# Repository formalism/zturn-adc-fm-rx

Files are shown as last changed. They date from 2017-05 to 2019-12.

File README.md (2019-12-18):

# zturn-adc-fm-rx
FM radio reciever by custom ADC/FM BPF board and [Z-turn board](http://www.myirtech.com/list.asp?id=502).

# Directory structure
 * FPGA : FPGA design which should be programmed to Z-turn board.
 * Firmware : programs to be run on Linux on Z-turn board.
      + adc-cap : communicates with adc-capture program.
      + ws-rust : use canvas.html to see FFT result (the functionality is similar to adc-cap and adc-capture program).
 * Sch : Schematics by KiCad
      + adc : ADC(LTC2292 by Linear Technology) board to be used with Z-turn board.
      + fm-bpf : FM bandpass active filter by PSA4-5043+ of Mini-Circuits.
 * PC : software run on Windows
      + adc-capture : communicates with above adc-cap firmware. Written in C#.
      + rf_demod : PC only implementation of FM demodulation. This program convers data captured by ADC to audio data. This program was written to verify algorithm to be implemented in FPGA.

Please see the following pages for more info.

https://www.living-in.tokyo/post/2018/2/new_fm_antenna/

https://www.living-in.tokyo/post/2017/09/new_adc_arrival/

https://www.living-in.tokyo/post/2017/08/adc_rev02/

https://www.living-in.tokyo/post/2017/07/fm_bpf3/

# License
MIT

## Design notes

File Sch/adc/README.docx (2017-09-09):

# PCB Spec

Layers: 4 layers

Material Details: FR4-Standard

Board Thickness: 1.6mm

Board Dimensions: Width 69.600mm x Height 43.800mm

Surface Finish: Lead Free HASL

Copper Thickness: 1oz (35um)

Soldermask Sides: Both

Soldermask Color: Green

Silkscreen Sides: Both

Silkscreen Color: White

# Description of the files contained:

*.drl (Drill Data)

*-drl.rpt (Drill Tool List)

*-drl_map.gbr (Drill Map)

*-Edge.Cuts.gbr (Board Outline)

*-top.pos (Top Layer Module Positions)

Top layer

*-F.Adhes.gbr (Gerber Top Layer Adhesives)

*-F.Cu.gbr (Gerber Top Layer)

*-F.Mask.gbr (Gerber Top Solder Mask)

*-F.Paste.gbr (Gerber Top Solder Paste for stencil)

*-F.SilkS.gbr (Gerber Top Silk)

2nd layer

*-In1.Cu.gbr (Gerber 2nd layer)

3rd layer

*-In2.Cu.gbr (Gerber 3rd layer)

Bottom layer

*-B.Adhes.gbr (Gerber Bottom Layer Adhesives)

*-B.Cu.gbr (Gerber Bottom Layer)

*-B.Mask.gbr (Gerber Bottom Solder Mask)

*-B.Paste.gbr (Gerber Bottom Solder Paste for stencil)

*-B.SilkS.gbr (Gerber Bottom Silk)

BOM file: zturn_adc.xlsx

# Note for Assembly

All the components are chosen carefully including passives. So use the part as-is where BOM column “Compatible parts can be used?” is marked “N”. If you cannot procure the parts as specified in BOM file, please let me know the suggested parts and their datasheets.

All the parts are mount on the TOP SIDE.

Do not load R29, R30 (and NO SOLDER).

4 center pads of U1, U6 should also be soldered.

CN3 is towards OUTSIDE of the PCB.

Take care of the orientation when mounting the following parts: U1, U2, U3, U4, U5, U6, X1, T1. Pin #1 is marked with triangle “△”.

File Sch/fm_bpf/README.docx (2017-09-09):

# PCB Spec

Layers: 2 layers (top and bottom)

Material Details: FR4-Standard

Board Thickness: 0.6mm (not 1.6mm!!)

Board Dimensions: Width 40.200mm x Height 20.800mm

Surface Finish: Lead Free HASL

Copper Thickness: 1oz (35um)

Soldermask Sides: Top

Soldermask Color: Green

Silkscreen Sides: Both

Silkscreen Color: White

# Description of the files contained:

*.drl (Drill Data)

*-drl.rpt (Drill Tool List)

*-drl_map.gbr (Drill Map)

*-Edge.Cuts.gbr (Board Outline)

*-top.pos (Position of the modules on Top Layer)

Top Layer

*-F.Adhes.gbr (Gerber Top Layer Adhesives)

*-F.Cu.gbr (Gerber Top Layer)

*-F.Mask.gbr (Gerber Top Solder Mask)

*-F.Paste.gbr (Gerber Top Solder Paste for stencil)

*-F.SilkS.gbr (Gerber Top Silk)

Bottom Layer

*-B.Adhes.gbr (Gerber Bottom Layer Adhesives)

*-B.Cu.gbr (Gerber Bottom Layer)

*-B.Mask.gbr (Gerber Bottom Solder Mask)

*-B.Paste.gbr (Gerber Bottom Solder Paste for stencil)

*-B.SilkS.gbr (Gerber Bottom Silk)

BOM file: fm_bpf.xlsx

# Note for Assembly

All the components are chosen carefully including passives. So use the part as-is where BOM column “Compatible parts can be used?” is marked “N”. If you cannot procure the parts as specified in BOM file, please let me know the suggested parts and their datasheets.

All the parts are mount on the TOP SIDE.

Because the PCB is thin, soldering on bottom side for the SMA connector is not necessary (top side is necessary).

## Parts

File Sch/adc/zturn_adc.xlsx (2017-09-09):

Reference | Value | Footprint | Datasheet | Type | Qty | Part | Manufacturer | Description | Compatible can be used? | Note
U1 | LTC2292 | 64QFN | http://cds.linear.com/docs/en/datasheet/229321fa.pdf | SMD | 1 | LTC2292CUP#PBF | Linear Technology | 12 Bit Analog to Digital Converter 2 Input 2 Pipelined 64-QFN (9x9) | N | Take Care of Rotation
P1 | CONN_02X40 | adc_lib:20021121-00080T4LF | http://portal.fciconnect.com/Comergent//fci/drawing/20021121.pdf | SMD | 1 | 20021121-00080T4LF | Amphenol FCI | CONN HEADER 80POS DL UNSHRD SMD | Y
J1,J3,J4 | JP2 |  | https://cdn.harwin.com/pdfs/M20-998.pdf | PTH | 3 | M20-9980245 | Harwin Inc. | DIL VERTICAL PC TAIL PIN HEADER 4 POS | Y
TP1,TP2,TP3,TP4 | TEST |  |  |  |  |  |  |  |  | Do Not Load
W1,W2,W3,W4,W5,W6 | TEST_1P |  | http://portal.fciconnect.com/Comergent//fci/drawing/68000.pdf | PTH | 6 | 68000-401HLF | Amphenol FCI | BERGSTIK II .100" SR STRAIGHT | Y
C9,C15,C16,C22,C23, C24,C26,C38,C39 | 0.1uF | 0603 | http://search.murata.co.jp/Ceramy/image/img/A01X/G101/ENG/GRM188R71H104JA93-01.pdf | SMD | 9 | GRM188R71H104JA93D | Murata Electronics North America | CAP CER 0.1uF ±5% 50V X7R 0603 | N
C3,C4,C5,C7,C8,C10,C11, C13,C14,C25,C29,C30, C41,C44,C46,C53 | 0.1uF | 0402 | http://search.murata.co.jp/Ceramy/image/img/A01X/G101/ENG/GRM155R71C104KA88-01.pdf | SMD | 16 | GRM155R71C104KA88J | Murata Electronics North America | CAP CER 0.1uF ±10% 16V X7R 0402 | N
C28,C42,C43,C45,C47 | 4.7uF | 0603 | http://ds.yuden.co.jp/TYCOMPAS/ut/detail.do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 | SMD | 5 | EMK107ABJ475KA-T | Taiyo Yuden | CAP CER 4.7uF ±10% 16V X5R 0603 | Y
C6,C31,C32,C40 | 2.2uF | 0402 | http://search.murata.co.jp/Ceramy/image/img/A01X/G101/ENG/GRM155R61A225KE95-01.pdf | SMD | 4 | GRM155R61A225KE95D | Murata Electronics North America | CAP CER 2.2µF ±10% 10V X5R 0402 | Y
C33,C34,C35,C36 | 1uF | 0402 | http://ds.yuden.co.jp/TYCOMPAS/ut/detail.do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 | SMD | 4 | EMK105BJ105KV-F | Taiyo Yuden | CAP CER 1uF ±10% 16V X5R 0402 | Y
C1,C2,C12,C20 | 1uF | 0603 | http://psearch.jp.murata.com/capacitor/product/GCM188R71E105KA64%23.pdf | SMD | 4 | GCM188R71E105KA64D | Murata Electronics North America | CAP CER 1uF ±10% 25V X7R 0603 | N
C17 | 12pF | 0603 | http://search.murata.co.jp/Ceramy/image/img/A01X/G101/ENG/GRM1885C1H120JA01-01.pdf | SMD | 1 | GRM1885C1H120JA01D | Murata Electronics North America | CAP CER 12pF ±5% 50V NP0 0603 | N
C18 | 1000pF | 0603 | http://search.murata.co.jp/Ceramy/image/img/A01X/G101/ENG/GRM188R71H102KA01-01.pdf | SMD | 1 | GRM188R71H102KA01D | Murata Electronics North America | CAP CER 1000pF ±10% 50V X7R 0603 | N
C37 | 8pF | 0402 | http://psearch.en.murata.com/capacitor/product/GJM1555C1H8R0CB01%23.pdf | SMD | 1 | GJM1555C1H8R0CB01D | Murata Electronics North America | CAP CER 8pF ±0.25pF 50V C0G/NP0 0402 | N
C21,C27 | 220uF | 1206 | http://search.murata.co.jp/Ceramy/image/img/A01X/G101/ENG/GRM31CR60J227ME11-01.pdf | SMD | 2 | GRM31CR60J227ME11L | Murata Electronics North America | CAP CER '220µF ±20% 6.3V X5R 1206 | Y
R1,R3,R4,R9,R12 | 22 | 0603 | https://industrial.panasonic.com/cdbs/www-data/pdf/RDA0000/AOA0000C304.pdf | SMD | 5 | ERJ-3EKF22R0V | Panasonic Electronic Components | 22 Ohm ±1% 0.1W, 1/10W Chip Resistor 0603 (1608 Metric) | Y
R25 | 2k | 0603 | https://industrial.panasonic.com/cdbs/www-data/pdf/RDA0000/AOA0000C304.pdf | SMD | 1 | ERJ-3EKF2001V | Panasonic Electronic Components | 2k Ohm ±1% 0.1W, 1/10W Chip Resistor 0603 (1608 Metric) | Y
R7,R8 | 25 | 0603 | https://industrial.panasonic.com/cdbs/www-data/pdf/RDA0000/AOA0000C304.pdf | SMD | 2 | ERJ-3EKF24R9V | Panasonic Electronic Components | 24.9 Ohm ±1% 0.1W, 1/10W Chip Resistor 0603 (1608 Metric) | N
R5,R6,R24 | 1k | 0603 | https://industrial.panasonic.com/cdbs/www-data/pdf/RDA0000/AOA0000C304.pdf | SMD | 3 | ERJ-3EKF1001V | Panasonic Electronic Components | 1k Ohm ±1% 0.1W, 1/10W Chip Resistor 0603 (1608 Metric) | Y
R29,R30 | DNL | 0603 |  |  |  |  |  |  |  | Do Not Load
R21,R22,R23 | 10k | 0402 | https://industrial.panasonic.com/cdbs/www-data/pdf/RDA0000/AOA0000C304.pdf | SMD | 3 | ERJ-2RKF1002X | Panasonic Electronic Components | 10k Ohm ±1% 0.1W, 1/10W Chip Resistor 0402 (1005 Metric) | Y
R2,R10,R11,R16,R27,R28 | 10k | 0603 | https://industrial.panasonic.com/cdbs/www-data/pdf/RDA0000/AOA0000C304.pdf | SMD | 6 | ERJ-3EKF1002V | Panasonic Electronic Components | 10k Ohm ±1% 0.1W, 1/10W Chip Resistor 0603 (1608 Metric) | Y
R18,R19 | 25 | 0402 | https://industrial.panasonic.com/cdbs/www-data/pdf/RDA0000/AOA0000C304.pdf | SMD | 2 | ERJ-2RKF24R9X | Panasonic Electronic Components | 24.9 Ohm ±1% 0.1W, 1/10W Chip Resistor 0402 (1005 Metric) | Y
R31,R32 | 12 | 0402 | https://industrial.panasonic.com/cdbs/www-data/pdf/RDA0000/AOA0000C304.pdf | SMD | 2 | ERJ-2RFK12R0X | Panasonic Electronic Components | 12 Ohm ±1% 0.1W, 1/10W Chip Resistor 0402 (1005 Metric) | N
R20,R33 | 0 | 0603 | https://industrial.panasonic.com/cdbs/www-data/pdf/RDA0000/AOA0000C304.pdf | SMD | 2 | ERJ-3GEY0R00V | Panasonic Electronic Components | jumper 0.1W 1/10W Chip Resistor 0603 (1608 Metric) | Y
R34 | 680 | 0603 | http://www.yageo.com/documents/recent/PYu-RC_Group_51_RoHS_L_7.pdf | SMD | 1 | RC0603FR-07680RL | Yageo | RES SMD 680 ohm ±1% 1/10W 0603 | Y
R17 | 1M | 0603 | http://www.yageo.com/documents/recent/PYu-RC_Group_51_RoHS_L_7.pdf | SMD | 1 | RC0603FR-071ML | Yageo | RES SMD 1M ohm ±1% 1/10W 0603 | Y
R13 | 33 | 0603 | http://www.yageo.com/documents/recent/PYu-RC_Group_51_RoHS_L_7.pdf | SMD | 1 | RC0603FR-0733RL | Yageo | RES SMD 33 ohm ±1% 1/10W 0603 | Y
X1 | TCXO | 4-SMD | http://www.taitien.com/wp-content/uploads/2015/12/XO-0076_TX.pdf | SMD | 1 | TXETBLSANF-40.0000 | Taitien | OSC TCXO 40.0000 MHz CLP S SMD | N | Take Care of Rotation
U4,U5 | NC7SVU04-SC70 | SC-70-5 | https://www.fairchildsemi.com/datasheets/NC/NC7SVU04.pdf | SMD | 2 | NC7SVU04P5X | Fairchild/ON Semiconductor | Inverter IC unbuff SC70-5 | N
T1 | ETC1-1-13 | 5-SMD | http://cdn.macom.com/datasheets/ETC1-1-13.pdf | SMD | 1 | ETC-1-1-13 | M/A-Com Technology Solutions | RF balun 4.5MHz-3GHz 1:1 5-SMD | N
U2,U3 | LP5907_SOT-23 | SOT-23-5 | http://www.ti.com/lit/ds/symlink/lp5907-q1.pdf | SMD | 2 | LP5907QMFX-3.0Q1 | Texas Instruments | Linear Voltage Regulator IC Positive Fixed Output 3V 250mA SOT-23-5 | N | Take Care of Rotation
L3 | 8.2uH | 1008 | http://www.murata.com/~/media/webrenewal/products/inductor/chip/tokoproducts/wirewoundmetalalloychiptype/m_dfe252012f.ashx | SMD | 1 | DFE252012F-8R2M=P2 | Murata Electronics North America | shielded FIXED IND 8.2uH 1.1A 410mOhm | N
L4 | 3.3uH | 1008 | http://www.murata.com/~/media/webrenewal/products/inductor/chip/tokoproducts/wirewoundmetalalloychiptype/m_dfe252012f.ashx | SMD | 1 | DFE252012F-3R3M=P2 | Murata Electronics North America | shielded FIXED IND 3.3uH 1.8A 135mOhm | N
U6 | NAU8822LYG | 32-QFN | http://www.nuvoton.com/resource-files/NAU8822LDataSheetRev1.9.pdf | SMD | 1 | NAU8822LYG | Nuvoton Technology Corporation of America | Audio Interface 24 b I²S, PCM 32-QFN (5x5) | N | Take Care of Rotation
CN1,CN2 | SMA | adc_lib:SMA_Edge | http://www.molex.com/pdm_docs/sd/732511150_sd.pdf | Edge Connector | 2 | 73251-1150 | Molex | CONN SMA RCPT STR 50OHM EDGE MNT | Y
CN3 | AudioJack | adc_lib:SJ-3523-SMT | http://www.cui.com/product/resource/sj-352x-smt-series.pdf | SMD | 1 | SJ-3523-SMT-TR | CUI Inc. | 3.50mm (0.141", 1/8", Mini Plug) - Headphone Phone Jack Stereo Connector Solder | Y
L1,L2,L7,L10 | Ferrite Bead | 0805 | https://product.tdk.com/info/en/catalog/datasheets/beads_commercial_power_mpz2012_en.pdf | SMD | 4 | MPZ2012S601AT000 | TDK Corporation | FERRITE BEAD 600 OHM 0805 1LN | Y
 |  |  |  | Total Components | 103
 |  |  |  | SMD | 92

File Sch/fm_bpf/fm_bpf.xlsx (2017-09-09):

Reference | Value | Footprint | Datasheet | Type | Qty | Part | Manufacturer | Description | Compatible parts can be used?
CN1,CN2 | SMA | Edge | https://belfuse.com/resources/Johnson/productinformation/pi-142-0701-881.pdf | Edge Connector | 2 | 142-0701-801 | Cinch Connectivity Solutions Johnson | SMA JACK STR 50ohm EDGE MNT | Y
U1 | LP5907_SOT-23 | SOT-23-5 | http://www.ti.com/lit/ds/symlink/lp5907-q1.pdf | SMD | 1 | LP5907QMFX-3.8Q1 | Texas Instruments | IC REG LDO 3.8V 0.25A SOT23-5 | N
U2 | PSA4-5043+ | MMM1362 | https://www.minicircuits.com/pdfs/PSA4-5043+.pdf | SMD | 1 | PSA4-5043+ | Mini-Circuits | ML AMPL / SURF MOUNT / RoHS | N
L1 | 330nH | 0603 | https://product.tdk.com/info/en/catalog/datasheets/inductor_commercial_standard_mlj1608_en.pdf | SMD | 1 | MLJ1608WR33JT000 | TDK Corporation | shielded FIXED IND ±5% 330nH 500mA 312mOhm (230MHz) | N
L2 | 27nH | 0603 | http://www.yuden.co.jp/productdata/catalog/en/mlci04_e.pdf | SMD | 1 | HK160827NJ-T | Taiyo Yuden | FIXED IND ±5% 27nH 300mA 450mOhm (1.4GHz) | N
L3 | 8.2uH | 1008 | http://www.murata.com/~/media/webrenewal/products/inductor/chip/tokoproducts/wirewoundmetalalloychiptype/m_dfe252012f.ashx | SMD | 1 | DFE252012F-8R2M=P2 | Murata Electronics North America | shielded FIXED IND ±20% 8.2uH 1.1A 410mOhm | N
L4 | 3.3uH | 0603 | https://media.digikey.com/pdf/Data%20Sheets/TDK%20PDFs/GLFR%20Series.pdf | SMD | 1 | GLFR1608T3R3M-LR | TDK Corporation | shielded FIXED IND ±20% 3.3uH 525mA 230mOhm | N
L5,L7 | 560nH | 0603 | https://product.tdk.com/info/en/catalog/datasheets/inductor_commercial_standard_mlj1608_en.pdf | SMD | 2 | MLJ1608WR56JT000 | TDK Corporation | shielded FIXED IND ±5% 560nH 400mA 520mOhm (170MHz) | N
L6 | 100nH | 0603 | https://product.tdk.com/info/en/catalog/datasheets/inductor_automotive_standard_mlf1608_en.pdf | SMD | 1 | MLF1608DR10JTD25 | TDK Corporation | shielded FIXED IND ±5% 100nH 200mA 350mOhm (450MHz) | N
C1,C4 | 1uF | 0603 | http://ds.yuden.co.jp/TYCOMPAS/ut/detail.do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 | SMD | 2 | TMK107B7105KA-T | Taiyo Yuden | CAP CER ±10% 1uF 25V X7R 0603 | N
C6,C7,C8 | 0.1uF | 0603 | http://search.murata.co.jp/Ceramy/image/img/A01X/G101/ENG/GRM188R71H104JA93-01.pdf | SMD | 3 | GRM188R71H104JA93D | Murata Electronics North America | CAP CER ±5% 0.1uF 50V X7R 0603 | N
C2 | 27pF | 0603 | http://search.murata.co.jp/Ceramy/image/img/A01X/partnumbering_e_01.pdf | SMD | 1 | GRM1885C1H270FA01D | Murata Electronics North America | CAP CER ±1% 27pF 50V C0G/NP0 0603 | N
C3 | 12pF | 0603 | http://search.murata.co.jp/Ceramy/image/img/A01X/partnumbering_e_01.pdf | SMD | 1 | GRM1885C1H120FA01D | Murata Electronics North America | CAP CER ±1% 12pF 50V C0G/NP3 0603 | N
C5 | 130pF | 0603 | http://search.murata.co.jp/Ceramy/image/img/A01X/partnumbering_e_01.pdf | SMD | 1 | GRM1885C1H131JA01D | Murata Electronics North America | CAP CER ±5% 130pF 50V C0G/NP3 0603 | N
C9 | 9pF | 0603 | http://search.murata.co.jp/Ceramy/image/img/A01X/partnumbering_e_01.pdf | SMD | 1 | GRM1885C1H9R0DA01D | Murata Electronics North America | CAP CER ±0.5pF 9pF 50V C0G/NP0 0603 | N
C11 | 68pF | 0603 | http://search.murata.co.jp/Ceramy/image/img/A01X/partnumbering_e_01.pdf | SMD | 1 | GRM1885C1H680FA01D | Murata Electronics North America | CAP CER ±1% 68pF 50V C0G/NP0 0603 | N
C12 | 100pF | 0603 | http://search.murata.co.jp/Ceramy/image/img/A01X/partnumbering_e_01.pdf | SMD | 1 | GRM1885C1H101JA01D | Murata Electronics North America | CAP CER ±5% 100pF 50V C0G/NP0 0603 | N
C10,C13,C14 | 5pF | 0603 | http://search.murata.co.jp/Ceramy/image/img/A01X/partnumbering_e_01.pdf | SMD | 3 | GRM1885C1H5R0BA01D | Murata Electronics North America | CAP CER ±0.1pF 5pF 50V C0G/NP0 0603 | N
R1 | 680 | 0603 | http://www.yageo.com/documents/recent/PYu-RC_Group_51_RoHS_L_7.pdf | SMD | 1 | RC0603FR-07680RL | Yageo | RES SMD 680 ohm 1% 1/10W 0603 | Y
R2 | 10k | 0603 | http://www.yageo.com/documents/recent/PYu-RC_Group_51_RoHS_L_7.pdf | SMD | 1 | RC0603FR-0710KL | Yageo | RES SMD 10k ohm 1% 1/10W 0603 | Y
W1,W2 | TEST_1P | PTH | http://portal.fciconnect.com/Comergent//fci/drawing/68000.pdf | PTH | 2 | 68000-401HLF | Amphenol FCI | BERGSTIK II .100" SR STRAIGHT | Y
 |  |  |  | total components | 29
 |  |  |  | SMD | 25

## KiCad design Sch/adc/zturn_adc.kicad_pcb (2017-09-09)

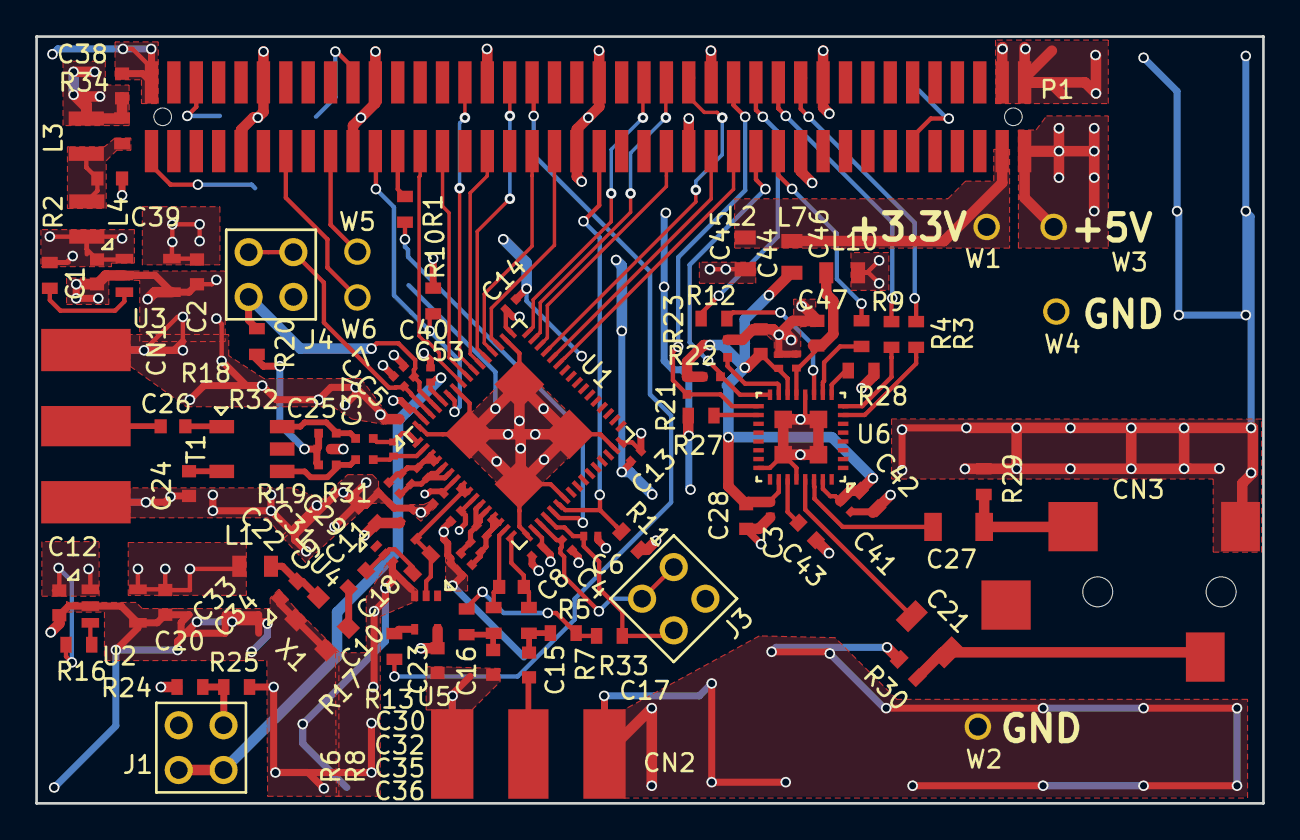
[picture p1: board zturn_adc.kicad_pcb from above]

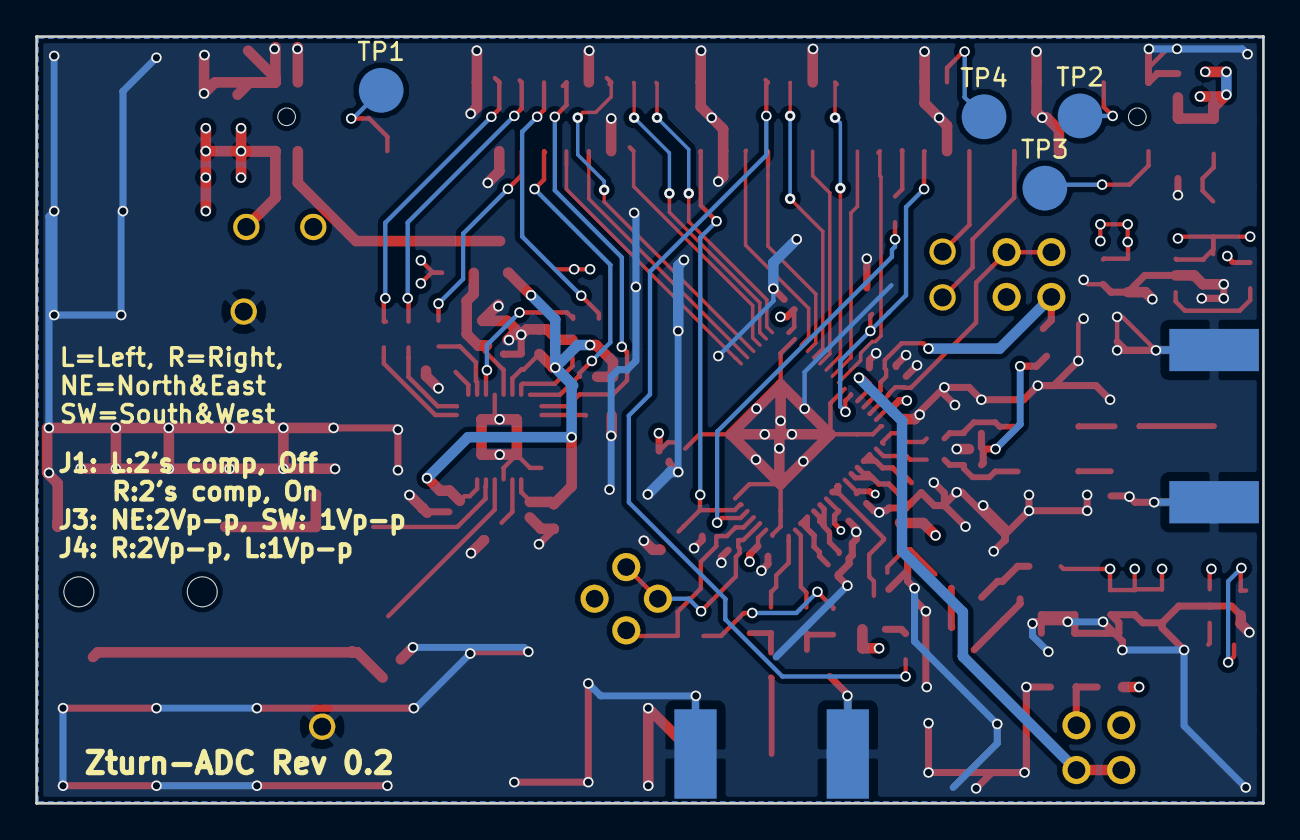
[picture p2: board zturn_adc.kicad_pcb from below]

Board: 4 copper layers, 69.6 x 43.5 mm, 109 parts (4 on the bottom side), 83 nets.

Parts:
C1, C2, C12, C20: 1uF X7R; C0603
C3, C4, C5, C7, C8, C10, C11, C13, C14, C41, C44, C46: 0.1uF; C0402
C6, C31, C32, C40: 2.2u; C0402
C9, C15, C16: 0.1uF; C0603
C17: 12pF; C0603
C18: 1000pF; C0603
C21, C27: 220uF; C1206
C22, C23, C24, C26, C38, C39: 0.1u; C0603
C25, C29, C30, C53: 0.1u; C0402
C28, C42, C43, C45, C47: 4.7uF; C0603
C33, C34, C35, C36: 1u; C0402
C37: 8p; C0402
CN1, CN2: SMA; SMA_Edge
CN3: AudioJack; SJ-3523-SMT
J1, J3, J4: JP2; M20-9980245
L1, L2, L7, L10: L; FB0805
L3: 8.2u; L1008
L4: 3.3u; L1008
P1: CONN_02X40; 20021121-00080T4LF
R1, R3, R4, R9, R12: 22; R0603
R2, R10, R11, R16, R27, R28: 10k; R0603
R5, R6, R24: 1k; R0603
R7, R8: 25; R0603
R13: 33; R0603
R17: 1M; R0603
R18, R19: 25; R0402
R20, R33: 0; R0603
R21, R22, R23: 10k; R0402
R25: 2k; R0603
R29, R30: DNL; R0603
R31, R32: 12; R0402
R34: 680; R0603
T1: ETC1-1-13
TP1, TP2, TP3, TP4: TEST; TL
U1: LTC2292
U2, U3: LP5907_SOT-23; LP5907
U4, U5: NC7SVU04-SC70; NC7SVU04-5SC70
U6: NAU8822LYG; NAU8822L
W1, W2, W3, W4, W5, W6: TEST_1P; 68000-401HLF
X1: TCXO

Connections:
+3V3: L2.2, L7.2, P1.3, W1.1
+5V: C38.1, L3.2, P1.1, R34.2, W3.1
/AudioDAC/VDDC: C46.1, C47.1, L10.1, U6.13
/AudioDAC/VREF: C43.1, U6.27
/CN/IO_B35_LN2: P1.24, R4.1
/CN/IO_B35_LN3: P1.29, U1.44
/CN/IO_B35_LN6: P1.34, U1.47
/CN/IO_B35_LN9: P1.45, U1.52
/CN/IO_B35_LN11: P1.49, U1.54
/CN/IO_B35_LN12: P1.48, U1.53
/CN/IO_B35_LN13: P1.55, U1.57
/CN/IO_B35_LN23: P1.79, TP3.1
/CN/IO_B35_LP1: P1.23, R9.1
/CN/IO_B35_LP2: P1.22, R3.1
/CN/IO_B35_LP3: P1.27, U1.43
/CN/IO_B35_LP4: P1.26, R12.2
/CN/IO_B35_LP5: P1.33, U1.46
/CN/IO_B35_LP6: P1.32, U1.45
/CN/IO_B35_LP8: P1.36, U1.48
/CN/IO_B35_LP9: P1.43, U1.51
/CN/IO_B35_LP13(MRCC): P1.53, U1.56
/CN/IO_B35_LP14: P1.52, U1.55
/CN/IO_B35_LP15: P1.57, R1.1
/CN/IO_B35_LP17: P1.63, W5.1
/CN/IO_B35_LP18: P1.62, TP4.1
/CN/IO_B35_LP19: P1.67, W6.1
/CN/IO_B35_LP24: P1.76, TP2.1
/CN/MUX: R1.2, U1.21
/CN/PS_MIO0: P1.11, TP1.1
/CN/SHDNA: P1.59, R10.1, U1.59
/CN/SHDNB: P1.39, R11.1, U1.22
/RF_in/CLK40M: R17.1, U1.8, U1.9, U4.4, U5.2
/RF_in/VCC5: C1.1, C12.1, L4.1, R2.1, R16.1, U2.1, U3.1
/RF_in/VCMA: C40.1, J4.3, R20.2, U1.61
/RF_in/VCMB: C6.1, J3.3, R33.1, U1.20
ADC_CLK: P1.46, R13.1
BCLK: R4.2, U6.8
DACIN: R9.2, U6.10
FS: R3.2, U6.7
GND: C1.2, C2.2, C3.2, C4.2, C5.2, C6.2, C7.2, C8.2, C9.1, C10.2, C11.2, C12.2, C13.2, C14.2, C16.2, C20.2, C22.2, C23.2, C24.1, C25.1, C28.2, C33.1, C34.1, C35.1, C36.1, C38.2, C39.2, C40.2, C41.2, C42.2, C43.2, C44.2, C45.2, C46.2, C47.2, C53.2, CN1.2, CN1.3, CN1.4, CN1.5, CN2.2, CN2.3, CN2.4, CN2.5, CN3.1, P1.2, P1.4, P1.20, P1.21, P1.30, P1.31, P1.40, P1.41, P1.50, P1.60, P1.61, P1.70, P1.71, P1.80, R10.2, R11.2, R23.2, R25.2, R27.2, R28.2, R29.2, R30.2, U1.17, U1.23, U1.31, U1.50, U1.58, U1.64, U1.65, U2.2, U2.4, U3.2, U3.4, U4.3, U5.3, U6.12, U6.24, U6.28, U6.33, W2.1, W4.1, X1.1, X1.2
MCLK: R12.1, U6.11
unnamed: C4.1, J3.2, J3.4, U1.19
unnamed: C5.1, J4.2, J4.4, U1.62
unnamed: C9.2, L1.2, X1.4
unnamed: C13.1, C14.1, L2.1, U1.32, U1.49
unnamed: C15.1, R5.2, R7.2
unnamed: C15.2, CN2.1
unnamed: C16.1, R6.2, R8.2
unnamed: C17.1, R7.1, U1.16
unnamed: C17.2, R8.1, U1.15
unnamed: C18.1, X1.3
unnamed: C18.2, R17.2, U4.2
unnamed: C21.1, U6.29
unnamed: C21.2, CN3.3, R30.1
unnamed: C24.2, T1.2
unnamed: C25.2, R18.2, R19.1, R20.1
unnamed: C26.1, T1.1
unnamed: C26.2, CN1.1
unnamed: C27.1, U6.30
unnamed: C27.2, CN3.2, R29.1
unnamed: C3.1, C28.1, C41.1, C42.1, C44.1, C45.1, L7.1, R21.1, R22.1, U6.14, U6.26, U6.31
unnamed: C29.1, C31.1, C33.2, U1.3, U1.4
unnamed: C29.2, C31.2, C34.2, U1.5, U1.6
unnamed: C30.1, C32.1, C35.2, U1.11, U1.12
unnamed: C30.2, C32.2, C36.2, U1.13, U1.14
unnamed: C37.1, R32.1, U1.1
unnamed: C37.2, R31.1, U1.2
unnamed: C39.1, L3.1, L4.2, R34.1
unnamed: C53.1, J1.2, J1.4, U1.60
unnamed: J1.3, R24.2, R25.1
unnamed: R2.2, U3.3
unnamed: R13.2, U5.4
unnamed: R16.2, U2.3
unnamed: R18.1, R32.2, T1.5
unnamed: R19.2, R31.2, T1.3
unnamed: R23.1, U6.15
unnamed: R27.1, U6.18
unnamed: R28.1, U6.9
unnamed: R5.1, R6.1, R33.2
SCL: P1.25, R22.2, U6.16
SDA: P1.28, R21.2, U6.17
VDD3: C2.1, C7.1, C8.1, C10.1, C11.1, J3.1, J4.1, L10.2, U1.7, U1.10, U1.18, U1.63, U3.5
VDD3_2: C20.1, C22.1, C23.1, J1.1, L1.1, R24.1, U2.5, U4.5, U5.5

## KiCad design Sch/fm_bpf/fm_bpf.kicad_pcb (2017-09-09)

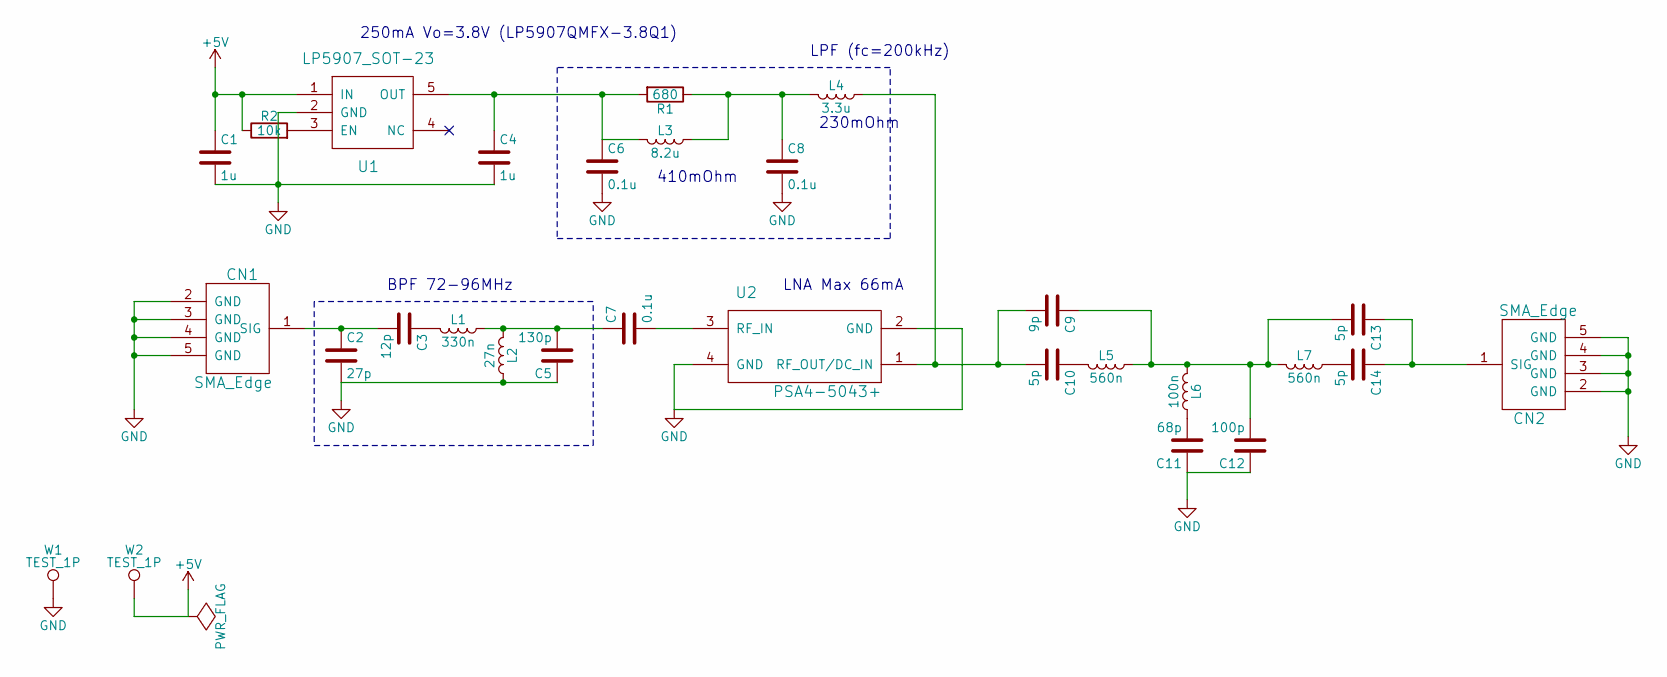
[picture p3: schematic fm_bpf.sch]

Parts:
C1, C4: 1u; C0603
C2: 27p; C0603
C3: 12p; C0603
C5: 130p; C0603
C6, C7, C8: 0.1u; C0603
C9: 9p; C0603
C10, C13, C14: 5p; C0603
C11: 68p; C0603
C12: 100p; C0603
CN1, CN2: SMA_Edge
L1: 330n; L0603
L2: 27n; L0603
L3: 8.2u; L1008
L4: 3.3u; L0603
L5, L7: 560n; L0603
L6: 100n; L0603
R1: 680; R0603
R2: 10k; R0603
U1: LP5907_SOT-23; LP5907
U2: PSA4-5043+; MMM1362
W1, W2: TEST_1P; 68000-401HLF

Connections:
+5V: C1.1, R2.1, U1.1 (IN), W2.1
GND: C1.2, C2.2, C4.2, C5.1, C6.2, C8.2, C11.1, C12.1, CN1.2 (GND), CN1.3 (GND), CN1.4 (GND), CN1.5 (GND), CN2.2 (GND), CN2.3 (GND), CN2.4 (GND), CN2.5 (GND), L2.1, U1.2 (GND), U2.2 (GND), U2.4 (GND), W1.1
unnamed: C2.1, C3.2, CN1.1 (SIG)
unnamed: C3.1, L1.2
unnamed: C4.1, C6.1, L3.2, R1.2, U1.5 (OUT)
unnamed: C5.2, C7.1, L1.1, L2.2
unnamed: C7.2, U2.3 (RF_IN)
unnamed: C8.1, L3.1, L4.2, R1.1
unnamed: C10.1, L5.2
unnamed: C9.2, C10.2, L4.1, U2.1 (RF_OUT/DC_IN)
unnamed: C11.2, L6.1
unnamed: C9.1, C12.2, C13.2, L5.1, L6.2, L7.2
unnamed: C13.1, C14.1, CN2.1 (SIG)
unnamed: C14.2, L7.1
unnamed: R2.2, U1.3 (EN)

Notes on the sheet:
250mA Vo=3.8V (LP5907QMFX-3.8Q1)
LPF (fc=200kHz)
BPF 72-96MHz
LNA Max 66mA
410mOhm
230mOhm

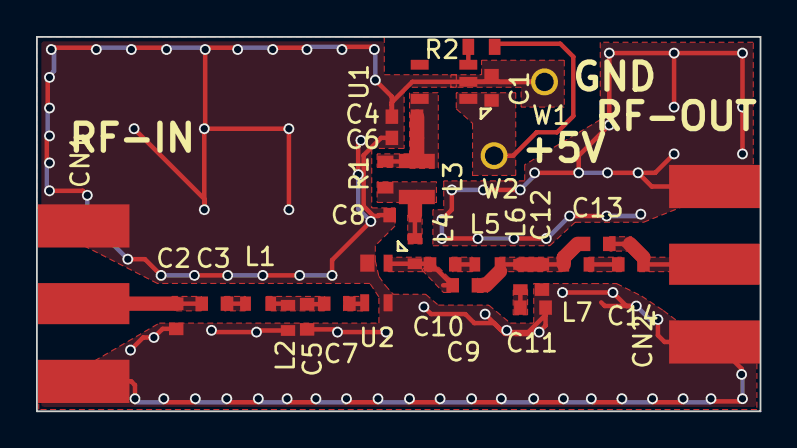
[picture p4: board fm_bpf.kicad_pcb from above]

Board: 2 copper layers, 40.2 x 20.8 mm, 29 parts (0 on the bottom side), 15 nets.

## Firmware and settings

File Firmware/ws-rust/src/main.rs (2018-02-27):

extern crate ws;
extern crate libc;

use ws::{listen, Handler, Result, Message, CloseCode, Handshake};
use ws::Message::{Text, Binary};
use ws::util::Token;
use std::fs::{OpenOptions, File};
use std::os::unix::fs::OpenOptionsExt;
use std::os::unix::io::{AsRawFd};
use std::f64;
use std::io;
use std::io::{Write, Read};
use std::ptr::{self, read_volatile, write_volatile};
use std::thread;
use std::sync::mpsc::{Sender, Receiver, channel};
use std::sync::Arc;
use std::slice;
use std::vec::Vec;
use std::boxed::Box;
use std::str::FromStr;

struct Server {
    out: ws::Sender,
    tx: Arc<Sender<i32>>,
    rx: Arc<Receiver<u32>>
}

const KB : libc::size_t = 1024;
const MB : libc::size_t = 1024*1024;
const MEM_SIZE : libc::size_t = 512*MB;
const MEM_OFFSET : libc::off_t = 512*MB as libc::off_t;
const ZERO_OFFSET : libc::off_t = 0;
const PAGE_SIZE : libc::size_t = 4096;
const SAMPLE_RATE : f32 = 40e+6;

// https://qiita.com/hukatama024e/items/1edd5c58ed68b5264d40

fn memmap() -> io::Result<*mut u32> {
    let mem_file = OpenOptions::new()
                    .read(true)
                    .write(true)
                    .custom_flags(libc::O_SYNC)
                    .open("/dev/mem")
                    .expect("can't open /dev/mem");
    unsafe {
        let ptr = libc::mmap(ptr::null_mut(),
                            MEM_SIZE, libc::PROT_READ | libc::PROT_WRITE,
                            libc::MAP_SHARED,
                            mem_file.as_raw_fd(),
                            MEM_OFFSET);        // second 512MB of the total of 1GB of DDR memory
        if ptr == libc::MAP_FAILED {
            Err(io::Error::last_os_error())
        }
        else
        {
            Ok(ptr as *mut u32)
        }
    }
}

fn uiomap(id : u32) -> (*mut u32, File) {
    let uio_file = OpenOptions::new()
                    .read(true)
                    .write(true)
                    .custom_flags(libc::O_SYNC)
                    .open(format!("/dev/uio{}", id))
                    .expect("can't open /dev/uio");
    unsafe {
        let ptr = libc::mmap(ptr::null_mut(),
                            PAGE_SIZE, libc::PROT_READ | libc::PROT_WRITE,
                            libc::MAP_SHARED,
                            uio_file.as_raw_fd(),
                            ZERO_OFFSET);
        if ptr == libc::MAP_FAILED {
            panic!("{}", io::Error::last_os_error())
        }
        (ptr as *mut u32, uio_file)
    }    
}

fn init_dds_frequency(freq : f32) -> () {
    let (uio_ptr, mut uio_file) = uiomap(1);
    let ratio = f64::from(freq / SAMPLE_RATE);
    for i in 0..400 {
        let s = (f64::from(i as i32) * f64::consts::PI*2.0*ratio).sin() * f64::from(1<<12);
        let c = (f64::from(i as i32) * f64::consts::PI*2.0*ratio).cos() * f64::from(1<<12);
        let si = s as i32;
        let ci = c as i32;
        let sc = (si<<16) | (ci & 0xFFFF);
        unsafe {
            write_volatile(uio_ptr.offset(i), sc as u32);
        }
    }
}

fn set_axi_dma_reg(reg_adr : *mut u32, size : u32, offset : u32) {
    let status_reg : *mut u32 = unsafe { reg_adr.offset(0) };
    let ien_reg : *mut u32 = unsafe { reg_adr.offset(1) };
    let done_reg : *mut u32 = unsafe { reg_adr.offset(2) };
    let offset_reg : *mut u32 = unsafe { reg_adr.offset(4) };
    let len_reg : *mut u32 = unsafe { reg_adr.offset(6) };

    unsafe {
        let status = read_volatile(status_reg); // clear ap_done
        write_volatile(ien_reg, 1);     // enable
        write_volatile(done_reg, 1);    // IP Interrupt enable reg
        write_volatile(offset_reg, offset/8);
        write_volatile(len_reg, size/8);
    }
}

fn start_axi_dma(reg_adr : *mut u32){
    let start_reg : *mut u32 = unsafe { reg_adr.offset(0) };
    unsafe {
        write_volatile(start_reg, 1);
    }
}

fn clear_interrupt(reg_adr : *mut u32){
    let intcl_reg : *mut u32 = unsafe { reg_adr.offset(3) };
    unsafe {
        write_volatile(intcl_reg, 1);
    }
}

fn wait_interrupt(uio_file : &mut File) -> (){
   let mut tmp = [0; 4];
   if 4 != uio_file.read(&mut tmp).unwrap() {    // wait interrupt
        panic!("failed read");
   }
}

impl Handler for Server {
    fn on_open(&mut self, _shake: Handshake) -> Result<()> {
        println!("on_open");
        Ok(())
    }
    fn on_timeout(&mut self, _event: Token) -> Result<()> {
        println!("on_timeout");
        Ok(())
    }
    fn on_message(&mut self, msg: Message) -> Result<()> {
//        println!("on_message");
        match msg {
            Text(t) => {
                let freq = f32::from_str(&t).unwrap();
                println!("{}", freq);
                init_dds_frequency(freq * 1e+6);
                let vec: Vec<u8> = vec![0; 1024];
                self.out.send(vec)
            },
            Binary(_v) => {
                let adr = self.rx.recv().unwrap();
//                println!("send Binary at address {}", adr);
//                mem::forget(adr);
                let mut vec : Vec<u8> = Vec::new();
                let ary : &'static [u8] = unsafe { slice::from_raw_parts(adr as *const u8, 256*KB) };
//                    let ary = Box::from_raw(adr as *mut u8);
//                    let mut vec : Vec<u8> = Vec::from_raw_parts(adr as *mut u8, 2*MB, 2*MB);
                vec.write(ary).expect("unable to write");
                let r = self.out.send(Binary(vec));
                self.tx.send(1);
                r
            }
        }
    }
    fn on_close(&mut self, _code: CloseCode, _reason: &str) {
    }
}

fn main() {
   println!("Hello, world!");
   let mapped_ptr : *mut u32 = memmap().expect("failed mmap");
   let (uio_ptr, mut uio_file) = uiomap(0);
   let one : [u8; 4] = [1, 0, 0, 0];

   let (tx_web, rx_cap) = channel();
   let (tx_cap, rx_web) = channel();

   let hdl = thread::spawn(move || {
       let tx = Arc::new(tx_web);
       let rx = Arc::new(rx_web);
       listen("192.168.0.90:3012",
                |out| Server { out: out, tx: Arc::clone(&tx), rx: Arc::clone(&rx) })
                .unwrap();
   });
   loop {
        set_axi_dma_reg(uio_ptr, 256*KB as u32, 512*MB as u32);   // capture 2MB (just for now)
        uio_file.write(&one).expect("write");            // enable interrupt
        start_axi_dma(uio_ptr);
        wait_interrupt(&mut uio_file);
        clear_interrupt(uio_ptr);
        tx_cap.send(mapped_ptr as u32);    // send start address
//        println!("send");
        let v = rx_cap.recv().unwrap();
   }
   //hdl.join().expect("join");
}

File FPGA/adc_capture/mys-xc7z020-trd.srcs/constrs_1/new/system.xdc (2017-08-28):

set_property IOSTANDARD LVCMOS33 [get_ports {IO_B34_LN[5]}]
set_property IOSTANDARD LVCMOS33 [get_ports {IO_B34_LN[4]}]
set_property IOSTANDARD LVCMOS33 [get_ports {IO_B34_LN[3]}]
set_property IOSTANDARD LVCMOS33 [get_ports {IO_B34_LN[2]}]
set_property IOSTANDARD LVCMOS33 [get_ports {IO_B34_LN[1]}]
set_property IOSTANDARD LVCMOS33 [get_ports {IO_B34_LP[5]}]
set_property IOSTANDARD LVCMOS33 [get_ports {IO_B34_LP[4]}]
set_property IOSTANDARD LVCMOS33 [get_ports {IO_B34_LP[3]}]
set_property IOSTANDARD LVCMOS33 [get_ports {IO_B34_LP[2]}]
set_property IOSTANDARD LVCMOS33 [get_ports {IO_B34_LP[1]}]
set_property IOSTANDARD LVCMOS33 [get_ports {IO_B35_LP[24]}]
set_property IOSTANDARD LVCMOS33 [get_ports {IO_B35_LP[23]}]
set_property IOSTANDARD LVCMOS33 [get_ports {IO_B35_LP[22]}]
set_property IOSTANDARD LVCMOS33 [get_ports {IO_B35_LP[21]}]
set_property IOSTANDARD LVCMOS33 [get_ports {IO_B35_LP[20]}]
set_property IOSTANDARD LVCMOS33 [get_ports {IO_B35_LP[19]}]
set_property IOSTANDARD LVCMOS33 [get_ports {IO_B35_LP[18]}]
set_property IOSTANDARD LVCMOS33 [get_ports {IO_B35_LP[17]}]
set_property IOSTANDARD LVCMOS33 [get_ports {IO_B35_LP[16]}]
set_property IOSTANDARD LVCMOS33 [get_ports {IO_B35_LP[15]}]
set_property IOSTANDARD LVCMOS33 [get_ports {IO_B35_LP[14]}]
set_property IOSTANDARD LVCMOS33 [get_ports {IO_B35_LP[13]}]
set_property IOSTANDARD LVCMOS33 [get_ports {IO_B35_LP[12]}]
set_property IOSTANDARD LVCMOS33 [get_ports {IO_B35_LP[11]}]
set_property IOSTANDARD LVCMOS33 [get_ports {IO_B35_LP[10]}]
set_property IOSTANDARD LVCMOS33 [get_ports {IO_B35_LP[9]}]
set_property IOSTANDARD LVCMOS33 [get_ports {IO_B35_LP[8]}]
set_property IOSTANDARD LVCMOS33 [get_ports {IO_B35_LP[7]}]
set_property IOSTANDARD LVCMOS33 [get_ports {IO_B35_LP[6]}]
set_property IOSTANDARD LVCMOS33 [get_ports {IO_B35_LP[5]}]
set_property IOSTANDARD LVCMOS33 [get_ports {IO_B35_LP[4]}]
set_property IOSTANDARD LVCMOS33 [get_ports {IO_B35_LP[3]}]
set_property IOSTANDARD LVCMOS33 [get_ports {IO_B35_LP[2]}]
set_property IOSTANDARD LVCMOS33 [get_ports {IO_B35_LP[1]}]
set_property IOSTANDARD LVCMOS33 [get_ports {IO_B35_LN[24]}]
set_property IOSTANDARD LVCMOS33 [get_ports {IO_B35_LN[23]}]
set_property IOSTANDARD LVCMOS33 [get_ports {IO_B35_LN[22]}]
set_property IOSTANDARD LVCMOS33 [get_ports {IO_B35_LN[21]}]
set_property IOSTANDARD LVCMOS33 [get_ports {IO_B35_LN[20]}]
set_property IOSTANDARD LVCMOS33 [get_ports {IO_B35_LN[19]}]
set_property IOSTANDARD LVCMOS33 [get_ports {IO_B35_LN[18]}]
set_property IOSTANDARD LVCMOS33 [get_ports {IO_B35_LN[17]}]
set_property IOSTANDARD LVCMOS33 [get_ports {IO_B35_LN[16]}]
set_property IOSTANDARD LVCMOS33 [get_ports {IO_B35_LN[15]}]
set_property IOSTANDARD LVCMOS33 [get_ports {IO_B35_LN[14]}]
set_property IOSTANDARD LVCMOS33 [get_ports {IO_B35_LN[13]}]
set_property IOSTANDARD LVCMOS33 [get_ports {IO_B35_LN[12]}]
set_property IOSTANDARD LVCMOS33 [get_ports {IO_B35_LN[11]}]
set_property IOSTANDARD LVCMOS33 [get_ports {IO_B35_LN[10]}]
set_property IOSTANDARD LVCMOS33 [get_ports {IO_B35_LN[9]}]
set_property IOSTANDARD LVCMOS33 [get_ports {IO_B35_LN[8]}]
set_property IOSTANDARD LVCMOS33 [get_ports {IO_B35_LN[7]}]
set_property IOSTANDARD LVCMOS33 [get_ports {IO_B35_LN[6]}]
set_property IOSTANDARD LVCMOS33 [get_ports {IO_B35_LN[5]}]
set_property IOSTANDARD LVCMOS33 [get_ports {IO_B35_LN[4]}]
set_property IOSTANDARD LVCMOS33 [get_ports {IO_B35_LN[3]}]
set_property IOSTANDARD LVCMOS33 [get_ports {IO_B35_LN[2]}]
set_property IOSTANDARD LVCMOS33 [get_ports {IO_B35_LN[1]}]
set_property IOSTANDARD LVCMOS33 [get_ports {LCD_DATA[15]}]
set_property IOSTANDARD LVCMOS33 [get_ports {LCD_DATA[14]}]
set_property IOSTANDARD LVCMOS33 [get_ports {LCD_DATA[13]}]
set_property IOSTANDARD LVCMOS33 [get_ports {LCD_DATA[12]}]
set_property IOSTANDARD LVCMOS33 [get_ports {LCD_DATA[11]}]
set_property IOSTANDARD LVCMOS33 [get_ports {LCD_DATA[10]}]
set_property IOSTANDARD LVCMOS33 [get_ports {LCD_DATA[9]}]
set_property IOSTANDARD LVCMOS33 [get_ports {LCD_DATA[8]}]
set_property IOSTANDARD LVCMOS33 [get_ports {LCD_DATA[7]}]
set_property IOSTANDARD LVCMOS33 [get_ports {LCD_DATA[6]}]
set_property IOSTANDARD LVCMOS33 [get_ports {LCD_DATA[5]}]
set_property IOSTANDARD LVCMOS33 [get_ports {LCD_DATA[4]}]
set_property IOSTANDARD LVCMOS33 [get_ports {LCD_DATA[3]}]
set_property IOSTANDARD LVCMOS33 [get_ports {LCD_DATA[2]}]
set_property IOSTANDARD LVCMOS33 [get_ports {LCD_DATA[1]}]
set_property IOSTANDARD LVCMOS33 [get_ports {LCD_DATA[0]}]
set_property IOSTANDARD LVCMOS33 [get_ports {LEDS[2]}]
set_property IOSTANDARD LVCMOS33 [get_ports {LEDS[1]}]
set_property IOSTANDARD LVCMOS33 [get_ports {LEDS[0]}]
set_property PACKAGE_PIN T11 [get_ports {IO_B34_LP[1]}]
set_property PACKAGE_PIN T10 [get_ports {IO_B34_LN[1]}]
set_property PACKAGE_PIN T12 [get_ports {IO_B34_LP[2]}]
set_property PACKAGE_PIN U12 [get_ports {IO_B34_LN[2]}]
set_property PACKAGE_PIN U13 [get_ports {IO_B34_LP[3]}]
set_property PACKAGE_PIN V13 [get_ports {IO_B34_LN[3]}]
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

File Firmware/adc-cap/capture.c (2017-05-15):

#include <math.h>
#include <stdlib.h>
#include <unistd.h>
#include <sys/types.h>
#include <sys/stat.h>
#include <sys/ioctl.h>
#include <stdio.h>
#include <fcntl.h>
#include <sys/mman.h>
#include <sys/socket.h>
#include <netinet/in.h>
#include <pthread.h>
#include <semaphore.h>
#include <errno.h>
#include <linux/i2c-dev.h>

#define SERVER_PORT (12345)

#define KB ((1024))
#define MB ((1024*1024))

/* 1bit shift-left */
#define NAU_DEVADR      (0x34)

static sem_t sem_cap_a, sem_cap_b, sem_xfer_a, sem_xfer_b;
static int running;

void socket_bind(int* sock0)
{
    struct sockaddr_in addr;
    struct sockaddr_in client;
    int len;

    *sock0 = socket(AF_INET, SOCK_STREAM, 0);
    addr.sin_family = AF_INET;
    addr.sin_port = htons(SERVER_PORT);
    addr.sin_addr.s_addr = INADDR_ANY;
    bind(*sock0, (struct sockaddr*)&addr, sizeof(addr));
}

void listen_and_accept(int* sock0, int* sock)
{
    struct sockaddr_in client;
    int len;

    listen(*sock0, 5);
    len = sizeof(client);
    *sock = accept(*sock0, (struct sockaddr*)&client, &len);
}

void set_axi_dma_reg(unsigned int* reg_addr, unsigned int size, unsigned int offset){
    unsigned int status = reg_addr[0]; /* clear ap_done */

    /* Global Interrupt Enable Register */
    reg_addr[1] = 1;                /* enable */
    /* IP Interrupt Enable Register */
    reg_addr[2] = 1;                /* ap_done */
    /* IP Interrupt Status Register */

    /* offset */
    reg_addr[4] = offset/8;

    /* len */
    reg_addr[6] = size/8;
}

void start_axi_dma(unsigned int* reg_addr){
    reg_addr[0] = 1;
}

void clear_interrupt(unsigned int* reg_addr){
    unsigned int status = reg_addr[3];
    reg_addr[3] = 1;                /* clear ap_done */
}

// initialize DDS memory (currently fixed 40MHz sampling)
void init_dds_frequency(float freq){
    int i;
    int uiofd;
    unsigned int* map_addr;
    double ratio = freq / 40e+6;

    uiofd = open("/dev/uio1", O_RDWR);
    if (uiofd < 0){
        perror("uio open:");
        goto exit;
    }
    map_addr = (unsigned int*)mmap(NULL, 32*KB, PROT_READ | PROT_WRITE, MAP_SHARED, uiofd, 0);
    if (!map_addr){
        fprintf(stderr, "mmap failed\n");
        goto exit;
    }
    for (i = 0; i < 400; i++){  /* 400 point is enough */
        int s = sin((double)i*M_PI*2.0*ratio) * (1<<12);
        int c = cos((double)i*M_PI*2.0*ratio) * (1<<12);
        int sc = (s<<16) | (c & 0xFFFF);
        printf("[i=%08d] sin=%d, cos=%d, sincos=%08X\n", i, s, c, sc);
        map_addr[i] = sc;
    }
 exit:
    return;
}

void parse_frequency(int fd){
    int len = 0;
    char buf[8];
    float freq;
    
    do{
        len += read(fd, &buf[len], 4-len);
    }while (len < 4);
    sscanf(buf, "%f", &freq);
    freq *= 1e+6;               /* to MHz */
    init_dds_frequency(freq);
}

void* cmd_thread_func(void* arg){
    int fd = *(int*)arg;
    char buf[16];
    int len;

    while (1){
        len = read(fd, buf, 1); /* read a byte */
        if (len < 1){           /* EOF or closed */
            running = 0;
            break;
        }
        switch (buf[0]){
        case 'F':                    /* set frequency: XX.X MHz */
            parse_frequency(fd);
            break;
        default:
            break;
        }
    }
}

void* thread_func(void* arg){
    int uiofd;
    unsigned int* map_addr;
    unsigned int one = 1;
	int i,j=0;
    unsigned int size = *(unsigned int*)arg;

    uiofd = open("/dev/uio0", O_RDWR);
    if (uiofd < 0){
        perror("uio open:");
        goto thread_exit;
    }
    map_addr = (unsigned int*)mmap(NULL, 4096, PROT_READ | PROT_WRITE, MAP_SHARED, uiofd, 0);
    if (!map_addr){
        fprintf(stderr, "mmap failed\n");
        goto thread_exit;
    }

    printf("size=%08X\n", size);

    while (running){
        //        printf("Write DMA registers\n");
        if (sem_wait(&sem_cap_a) < 0){
            break;
        }
        set_axi_dma_reg(map_addr, size, (512*MB));
        write(uiofd, &one, 4);       /* enable interrupt */
        //        printf("Start DMA(A)!!\n");
        start_axi_dma(map_addr);
        
        if (4 != read(uiofd, &i, 4)) /* wait interrupt */
            perror("uio read:");
        
        //        printf("DMA Done\n");
        clear_interrupt(map_addr);
        if (sem_post(&sem_xfer_a) < 0){
            break;
        }

        if (sem_wait(&sem_cap_b) < 0){
            break;
        }
        set_axi_dma_reg(map_addr, size, ((512+256)*MB));
        write(uiofd, &one, 4);       /* enable interrupt */
        //        printf("Start DMA(B)!!\n");
        start_axi_dma(map_addr);
        
        if (4 != read(uiofd, &i, 4)) /* wait interrupt */
            perror("uio read:");
        clear_interrupt(map_addr);
        if (sem_post(&sem_xfer_b) < 0){
            break;
        }
    }

 thread_exit:
    close(uiofd);
    pthread_exit(NULL);
}

int write_reg(int fd, int adr, int data){
    char buf[3];

    buf[0] = (adr<<1) | ((data&0x100)>>8);
    buf[1] = data & 0xFF;
    if (write(fd, buf, 2) < 0){
        return -1;
    }
    return 0;
}

int read_reg(int fd, int adr){
    char buf[3];

    buf[0] = (adr<<1);
    if (write(fd, buf, 1) < 0){
        perror("write");
        return -1;
    }
    if (read(fd, buf, 2) < 0){
        perror("read");
        return -1;
    }
    return (buf[0]<<8) | buf[1];
}
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

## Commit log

2017-02-10 Add Initial Schematic
    [FX3.sch, zturn_adc.sch]
2017-02-12 FX3 clock,reset,cn
    [FX3_clk_reset_cn.sch, zturn_adc.kicad_pcb, zturn_adc.sch]
2017-02-12 Add DQ and 80-pin
    [FX3_DQ.sch, FX3_clk_reset_cn.sch, FX3_power.sch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]
2017-02-13 Add RF part
    [FX3_DQ.sch, FX3_clk_reset_cn.sch, FX3_power.sch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]
2017-02-14 Add ADC, CN1/CN2
    [FX3_DQ.sch, RF_in.sch]
2017-02-15 Add 1.2V
    [FX3VDD.sch, FX3_DQ.sch, FX3_GPIO.sch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]
2017-02-16 moved to fx3 dir
    [FX3.sch, FX3VDD.sch, FX3_DQ.sch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]
2017-02-16 separate FX3 and ADC
    [CN.sch, FX3.sch, FX3VDD.sch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]
2017-02-16 Add resistors for ADC out
    [CN.sch, zturn_adc.sch]
2017-02-17 Add B-ch of the ADC
    [RF_in.sch, zturn_adc.sch]
2017-02-18 Almost finished except Audio
    [CN.sch, RF_in.sch, zturn_adc.sch]
2017-02-18 Fix MODE pin voltage of the ADC
    [CN.sch, RF_in.sch]
2017-02-18 Changed LDO
    [RF_in.sch]
2017-02-18 Select nap mode for each channel
    [CN.sch]
2017-02-19 DAC in progress
    [AudioDAC.sch, CN.sch, RF_in.sch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]
2017-02-19 Audio DAC almost done. Is it OK to set VDDC=3.3V?
    [AudioDAC.sch, CN.sch]
2017-02-19 Schematics done
    [AudioDAC.sch, CN.sch, RF_in.sch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]
2017-02-19 Add netlist and BOM
    [AudioDAC.sch, CN.sch, RF_in.sch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]
2017-02-20 Adding parts
    [AudioDAC.sch, CN.sch, RF_in.sch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]
2017-02-20 Add parts
    [AudioDAC.sch, CN.sch, RF_in.sch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]
2017-02-20 Changed TCXO->MEMS TCXO. BOM finished
    [AudioDAC.sch, CN.sch, RF_in.sch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]
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2017-02-21 Done before capacitors
    [zturn_adc.xlsx]
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2017-02-22 Assigned footprint to all the parts
    [AudioDAC.sch, CN.sch, RF_in.sch]
2017-02-22 Fixed footprint for TP
    [zturn_adc.kicad_pcb]
2017-02-22 Moved parts
    [zturn_adc.kicad_pcb]
2017-02-23 Routing in progress
    [AudioDAC.sch, RF_in.sch, zturn_adc.kicad_pcb]
2017-02-24 modify layout
    [zturn_adc.kicad_pcb]
2017-02-24 layout more
    [AudioDAC.sch, CN.sch, RF_in.sch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]
2017-02-24 Fix RA footprint
    [CN.sch, zturn_adc.kicad_pcb, zturn_adc.xlsx]
2017-02-26 Add routing
    [CN.sch, zturn_adc.kicad_pcb]
2017-02-27 done except GND net
    [AudioDAC.sch, RF_in.sch, zturn_adc.kicad_pcb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]
2017-02-27 Apply some design rules
    [RF_in.sch, zturn_adc.kicad_pcb]
2017-02-28 Changed footprint for the Audio DAC. Silk arrangement
    [AudioDAC.sch, zturn_adc.kicad_pcb]
2017-02-28 length matched within 3.63mm on ADC output
    [zturn_adc.kicad_pcb]
2017-02-28 moved jumper
    [zturn_adc.kicad_pcb]
2017-02-28 Add mounting hole
    [zturn_adc.kicad_pcb]
2017-02-28 Add pour GND
    [zturn_adc.kicad_pcb]
2017-03-01 Modify footprint to include 1-pin indicator. Routing almost done.
    [zturn_adc.kicad_pcb]
2017-03-01 Removed all *relevant* design rule warnings.
    [zturn_adc.kicad_pcb]
2017-03-01 Add some GND guards
    [zturn_adc.kicad_pcb]
2017-03-01 Removed GND pour on the backside
    [zturn_adc.kicad_pcb]
2017-03-01 Changed to SMD type. Update BOM
    [zturn_adc.kicad_pcb, zturn_adc.xlsx]
2017-03-01 Modify 3V3 pour
    [zturn_adc.kicad_pcb]
2017-03-01 Output manufacturing data
    [zturn_adc.kicad_pcb]
2017-03-02 Modify footprint for CDCLVC1102. Changed width of ADC_CLK.
    [zturn_adc.kicad_pcb]
2017-03-02 Add R0402
    [zturn_adc.xlsx]
2017-03-02 Changed some resistors to 0402.
    [AudioDAC.sch, zturn_adc.kicad_pcb, zturn_adc.xlsx]
2017-03-02 Flipped capacitors around audio DAC
    [zturn_adc.kicad_pcb]
2017-03-02 Flipped all the parts to the TOP. TODO: change C17,C39 to 0402 size
    [zturn_adc.kicad_pcb, zturn_adc.xlsx]
2017-03-03 Improve layout
    [zturn_adc.kicad_pcb]
2017-03-03 Modify power plane
    [zturn_adc.kicad_pcb]
2017-03-04 Fixed C0603/1206 footprint
    [zturn_adc.kicad_pcb, zturn_adc.xlsx]
2017-03-04 Reviewed footprint for C0402/L0603
    [zturn_adc.kicad_pcb]
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2017-03-05 Sent to Elecrow again
    [zturn_adc.kicad_pcb]
2017-03-06 Fixed footprint for JTAG CN
    [zturn_adc.kicad_pcb]
2017-03-08 Changed zone clearance to 0.3mm. Add silkscreen of the revision.
    [zturn_adc.kicad_pcb]
2017-03-08 Fixed GND short of pin 80
    [CN.sch, zturn_adc.kicad_pcb]
2017-03-08 Moved reference caps close to ADC
    [zturn_adc.kicad_pcb]
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2017-04-10 Fix FIR filter (probably...)
2017-04-16 Fix decimal point bug. Add initialization for sim
    [capture.c]
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2017-05-01 de-emphasis working?? But high-frequency is not suppressed as expected, so it still might have bugs. TODO: sim
    [design_1_wrapper.v]
2017-05-03 Fixed de-emphasis. Add testbench for de-emphasis
    [system.xdc]
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2017-06-29 Modification in progress. Changed clock gen.
    [AudioDAC.sch, CN.sch, RF_in.sch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]
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2017-07-01 Add pull-down to BP net. Remove RF amp of 2nd input to the ADC.
    [CN.sch, RF_in.sch]
2017-07-25 Analog front end is removed from the ADC board. ADC board is done
    [AudioDAC.sch, CN.sch, RF_in.sch]
2017-07-27 Add new PCB of RF front end (FM BPF)
    [fm_bpf.sch]
2017-07-29 Start BOM for BPF
    [fm_bpf.sch, fm_bpf.xlsx]
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2017-07-31 PCB layout in progress
    [fm_bpf.kicad_pcb, fm_bpf.sch]
2017-08-01 FM BPF layout almost done
    [fm_bpf.kicad_pcb]
2017-08-01 Start redesign of ADC board
    [AudioDAC.sch, CN.sch, RF_in.sch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]
2017-08-02 ADC PCB layout in progress
    [AudioDAC.sch, CN.sch, RF_in.sch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]
2017-08-02 ADC Layout done except GND
    [CN.sch, zturn_adc.kicad_pcb]
2017-08-03 Removed unnecessary resistor array
    [CN.sch, zturn_adc.kicad_pcb]
2017-08-03 Changed MUX routing layout
    [zturn_adc.kicad_pcb]
2017-08-07 Add GND and more layout
    [AudioDAC.sch, CN.sch, RF_in.sch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]
2017-08-08 layout cuts and more
    [zturn_adc.kicad_pcb]
2017-08-08 ADC board layout probably done
    [zturn_adc.kicad_pcb]
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2017-08-14 BOM list for ADC board is done
    [RF_in.sch, signal_length.xlsx, zturn_adc.kicad_pcb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]
2017-08-14 Fill GND on bottom side
    [zturn_adc.kicad_pcb]
2017-08-14 Fixed BOM for FM BPF
    [fm_bpf.xlsx]
2017-08-14 Add GND on top side
    [fm_bpf.kicad_pcb]
2017-08-14 Fix BOM for BPF and layout
    [fm_bpf.kicad_pcb, fm_bpf.sch, fm_bpf.xlsx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]
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2017-08-14 Add SMD property to the modules
    [fm_bpf.kicad_pcb]
2017-08-15 Add Qty column to BOM. Add SMD attribute to ADC board
    [fm_bpf.xlsx, zturn_adc.kicad_pcb, zturn_adc.xlsx]
2017-08-15 Add 2 test headers
    [AudioDAC.sch, CN.sch, RF_in.sch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]
2017-08-15 Add revision marking to BPF
    [fm_bpf.kicad_pcb]
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2017-08-18 Improve layout and manufacture
    [zturn_adc.kicad_pcb]
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2018-02-19 Repetitive transfer works. Fixed segfault (using wrong mapped address was the main reason)
    [main.rs]
2018-02-22 Fixed memory leak in browser
    [main.rs]
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
